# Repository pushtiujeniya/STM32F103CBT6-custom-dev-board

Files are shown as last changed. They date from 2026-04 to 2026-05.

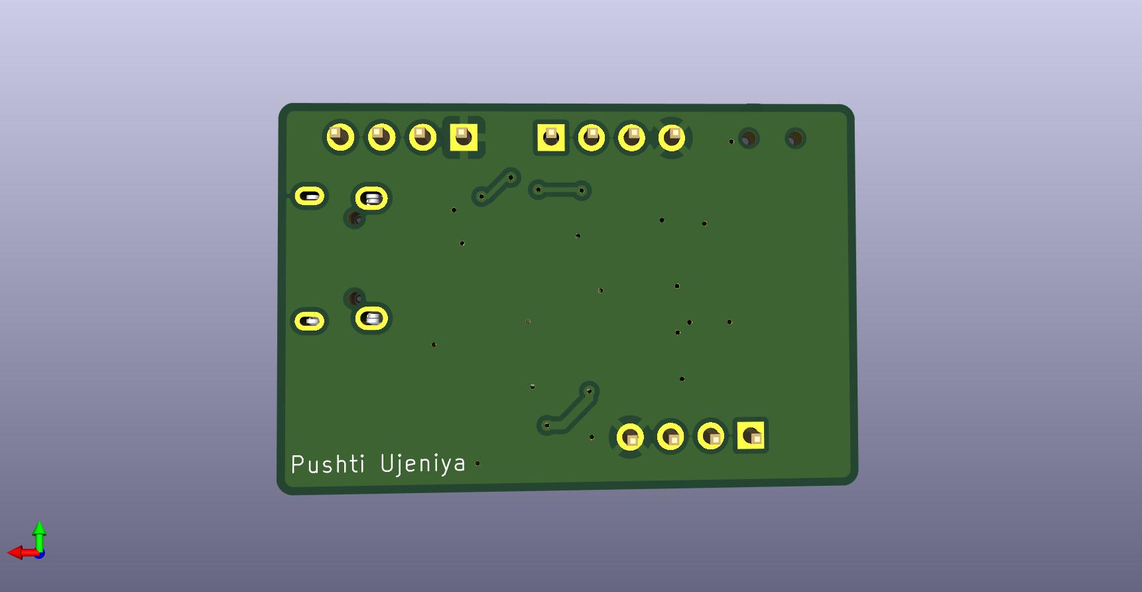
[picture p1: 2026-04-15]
3D_view/3D_bottom view.jpg

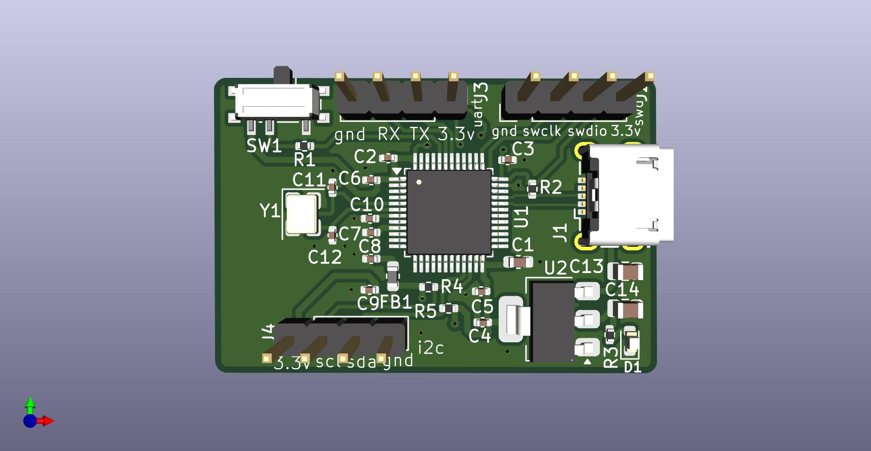
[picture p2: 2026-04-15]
3D_view/3D_top view.jpg

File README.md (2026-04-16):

# **STM32F103 custom development board**

This project contains custom development board based on the STM32F103 microcontroller.This baord created using kicad 9.0 software with proper routing , signal integrity, differential pair routing of USB connection.

## **Features**
- STM32F103 microcontroller
- Onboard 3.3V linear voltage regulator(AMS1117-3.3)
- Onboard Led indication on 3.3V power supply
- Micro USB interface for power and communication
- SWD interfacae for debugging and programming
- UART and I2C breakout headers
- Decoupling capacitors placed for stable operation
- External crystal oscillator with load capacitors
- MCU reser switch
- Clean PCB layout with proper grouding and differential routing for mico USB connection
- Board size: 35.5 mm X 23.6 mm

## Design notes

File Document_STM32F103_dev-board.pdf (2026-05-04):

STM32F103CBT6

STM32F103 custom development board
This project contains custom development board based on the STM32F103 microcontroller.This baord created using kicad 9.0 software with proper routing , signal integrity, differential pair routing of USB connection.

Features
STM32F103 microcontroller
Onboard 3.3V linear voltage regulator(AMS1117-3.3) Onboard Led indication on 3.3V power supply Micro USB interface for power and communication SWD interfacae for debugging and programming UART and I2C breakout headers
Decoupling capacitors placed for stable operation
External crystal oscillator with load capacitors
MCU reser switch
Clean PCB layout with proper grounding and differential routing for mico USB connection Board size: 35.5 mm X 23.6 mm

LDO power supply section

Pinout of LDO AMS1117-3.3
Vin
Vout
Gnd

Both vin and vout need decoupling capacitors connected with it Gnd connects directly with ground
Input voltage= 4.5V to 12V DC
Output voltage=3.3V

Here LDO is linear voltage regulator it converts the extra voltage into heat So as the heat is generating the efficiency decreases

Here 5v to 3.3v LDO conversion
Efficiency = vout/vin
=3.3/ 5
=66%
AMS1117-3.3
This LDO will give output as 3.3 v

As its voltage drop is high .>=1v
Here both vin and vout pins of the LDO needed decoupling capacitors
In datasheet 10uF decoupling capacitors mentioned which is minimum value of capacitor need to use
So for good stability 22uF is used
This generated 3.3V output of LDO is goes into MCU power on pin
By giving 3.3V the MCU gets power on
There is one LED with 1.5kohm resistor protection is connected at 3.3v output of an LDO to identify that 3.3v is available in LDO

USB_B micro

Pinout of USB B micro connector

D+ for data +
D- for data -
GND for ground
Vbus for +5v from USB
Shield= connects with gnd
Shield is metal holo part of the USB
Or shield can be connected with one resistor and one capacitor value for good ESD protection ID for different mode
ID=floating= device mode
ID=connect with GND= host mode

In device mode the host will control to USB Usb will respond to the host (PC)

Host mode
In this host will control everything

Pin 32 and pin33 of stm32f103 is used for USB connection

WHY PULL UP RESISTOR ON USB_D+ LINE REQUIRED
This pull up resistor tells to the host that device is connected
Without pull up resistor the host (PC) won’t know that device is connected

If pull up resistor is connected with D+ and D-

If pull up resistor is connected with D+ then USB will work in full speed (12 mbps)
If pull up resistor is connected with D- then USB will work in low speed device (1.5 mbps)

STM32F103 MCU

Pinout

vdd= digital power 3.3v
vss=gnd
vdda= analog power 3.3v
vssa= gnd
NRST= reset (active low)
BOOT0= boot mode select
PB2 (BOOT1) = secondary boot config

Clock pins
PD0= oscillator input= crystal input
PD1= oscillator output= crystal output Connect 4 to 16mhz external crystal range

Port A(PA0 to PA15)
ADC input, USART, SPI etc

Port B(PB0 to PB15)
I2c, spi, gpio

Port C( PC13 to PC15)
Low power pins , used for LED connection Switch connection

PA9= USART TX
PA10= USART RX

PB6= I2C SCL
PB7=I2C SDA

PA5= SPI SCK
PA6= SPI MISO
PA7= SPI MOSI

PA13= SWDIO
PA14=SWCLK
Used for programming via st link

PC14
PC15 CRYSTAL

VBAT= back up battery connection
If battery is not connected then connect vbat with your input voltage either vdd or VDDA

Name structure of STM32
STM32F103
This 1 indicate low power speed

STM32F401
This 4 indicate higher speed compare to STM32F103

STM32L= L for ultra low power
STM32WB= WB indicates for wireless conenction supported MCU

VDD pin of the MCU
Each vdd pin required decoupling capacitors connected with it 0.1uf for each vdd pin to remove high frequency noise
10uf for bulk energy storage and to remove low frequency noise

VDDA pin for analog input
VDD for digital power

Why VDD and VDDA two separate supply given in MCU
If VDD and VDDA is not separate out then digital noisy signal enter into analog circuits which cause wrong measurement of the ADC value
This occurs wrong value for sensors
So VDDA is very sensitive to noise so must be clean and need to separate out the power supply from VDD

WHY FERRITE BEAD IS CONNECTED ONLY WITH VDDA SECTION
As the ferrite bead will stop noise to enter into digital section and will provide clean path Digital circuit needs fast switching and instant current if ferrite bead is connected with digital circuit then it will resist high current frequency and will slow down the current delivery therefore don’t connect ferrite bead with it

PIN HEADER FOR SWD, USART, I2C

For debugging perspective there is swd pin header connection

Usart, i2c are for external connection of sensors

PCB LAYOUT
2 layer pcb

The track width for power rail is 0.5mm which is capable of carrying current up to 2A And other signal track width is 0.3mm

Front copper layer and bottom copper layer is apply with gnd solid plane

GND vias connection
Every gnd pad is connected with gnd vias so that the return current path loop remain short and tight

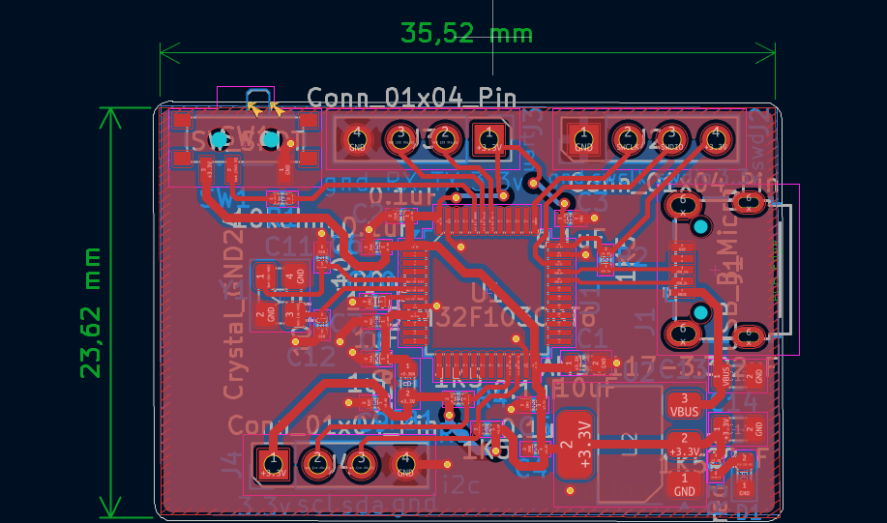
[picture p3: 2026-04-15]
Layout_front.png

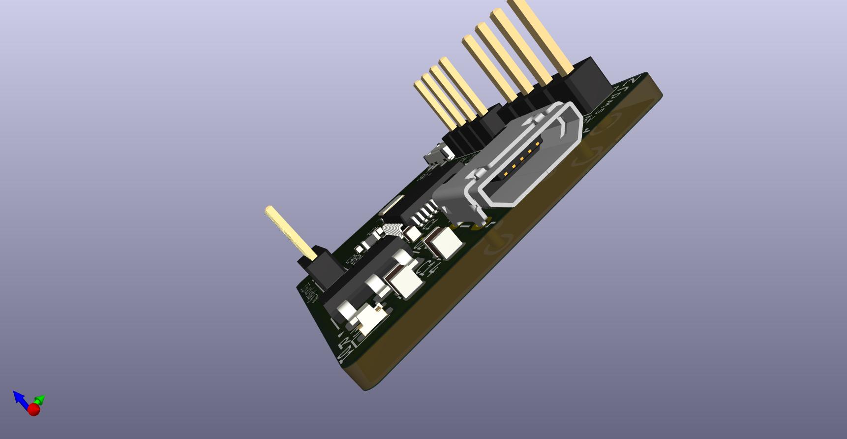
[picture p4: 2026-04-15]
3D_view/3D_microusb view.jpg

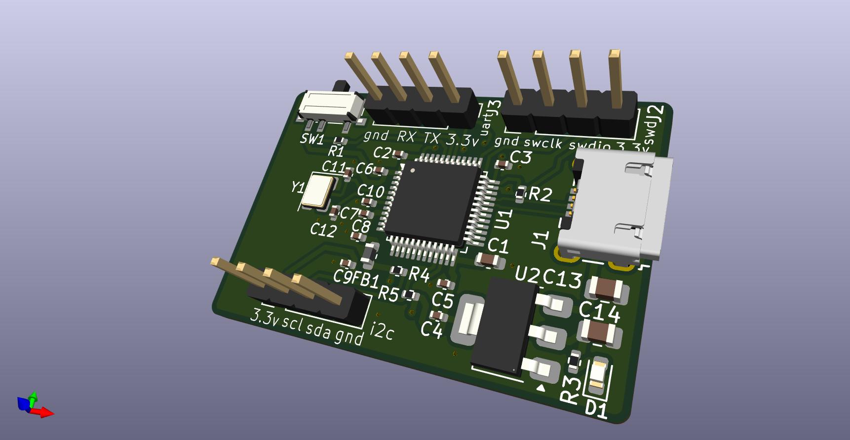
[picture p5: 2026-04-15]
3D_view/3D_side view.jpg

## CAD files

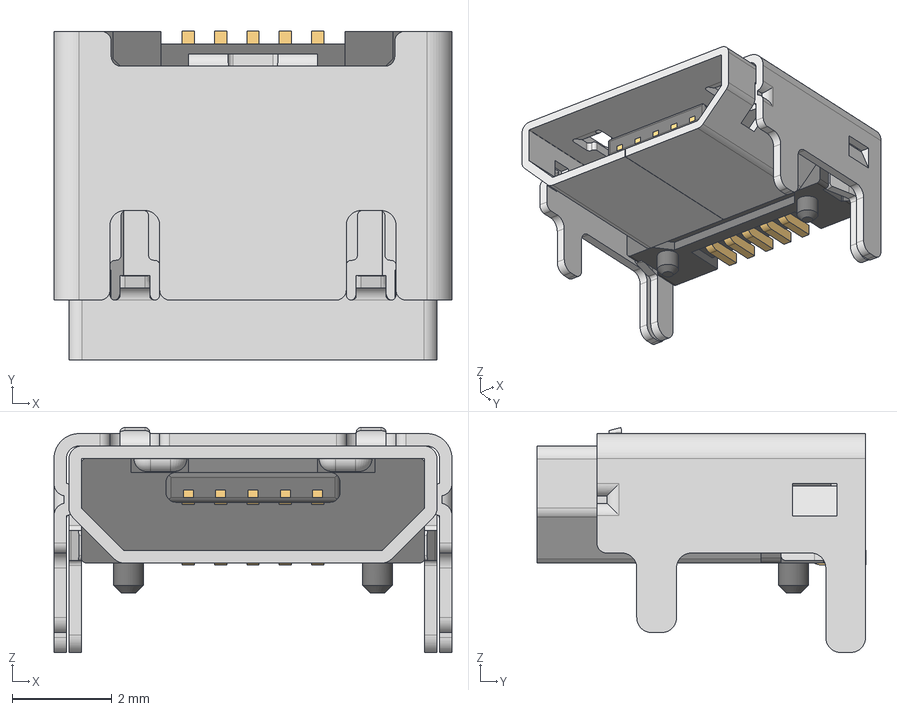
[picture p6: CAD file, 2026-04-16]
External library/629105150521+%28rev1%29.stp
8.00 x 6.60 x 4.52 mm
629105150521_Housing
629105150521_Pin1 x 4
629105150521_Pin2
629105150521_Shielding2
629105150521_Shielding

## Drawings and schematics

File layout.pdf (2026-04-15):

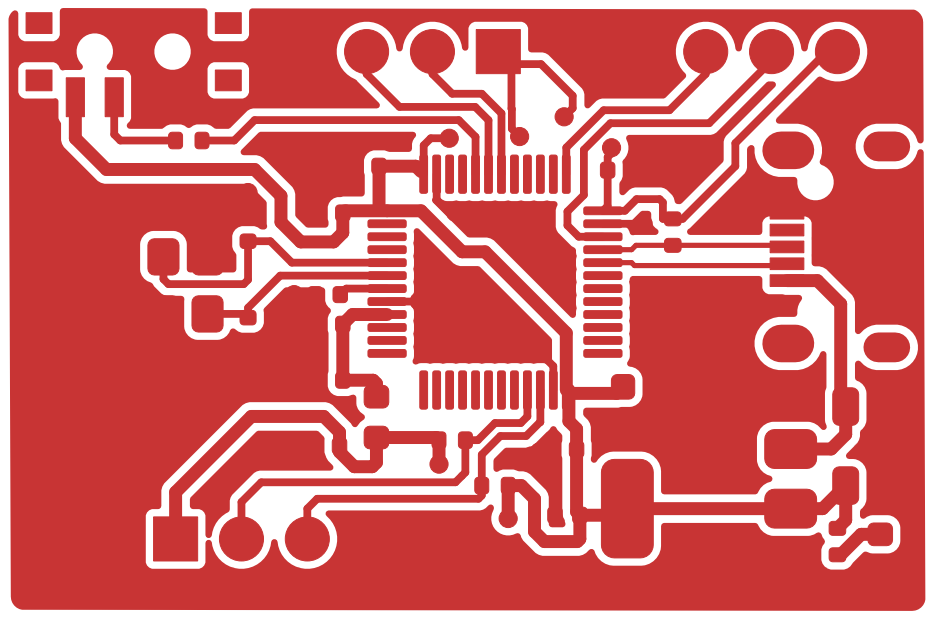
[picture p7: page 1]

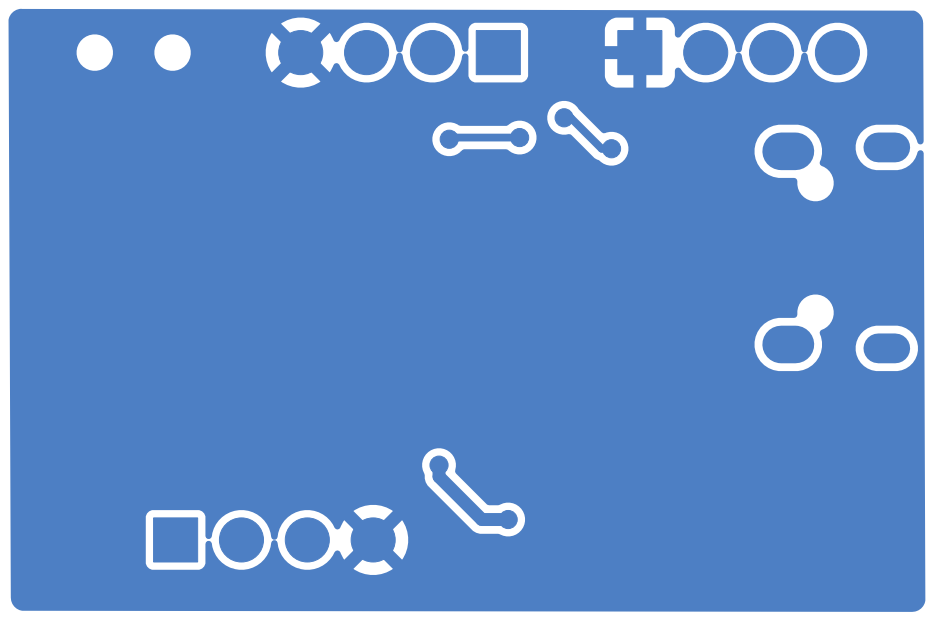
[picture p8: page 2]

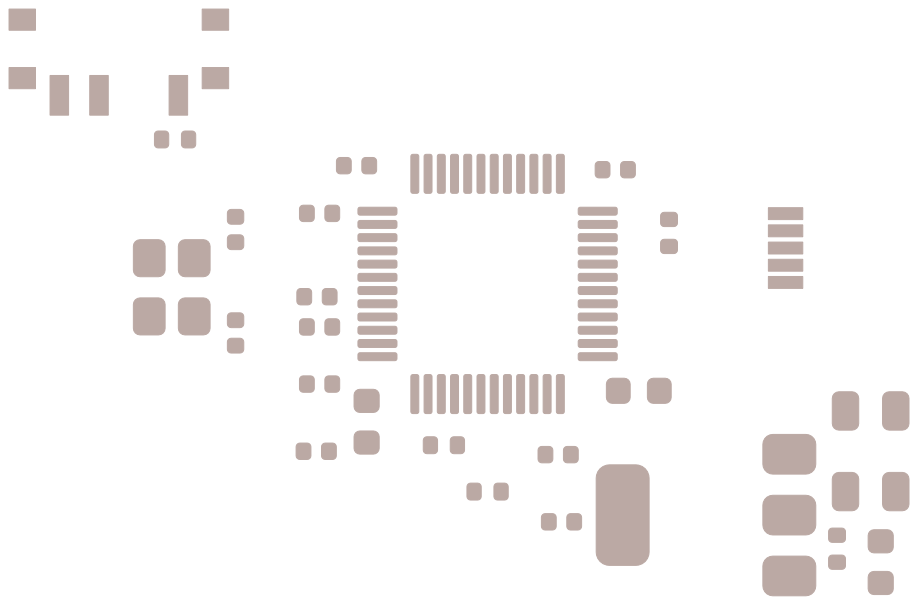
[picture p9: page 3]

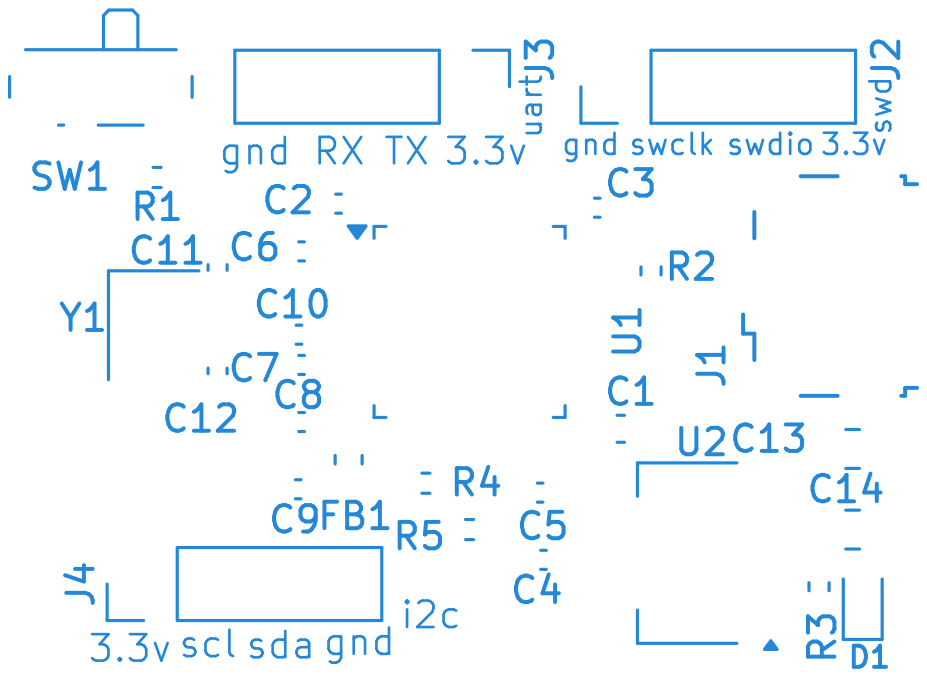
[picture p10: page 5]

uart swd gnd RX TX 3.3v gnd swclk swdio 3.3v 3.3v scl sda gnd

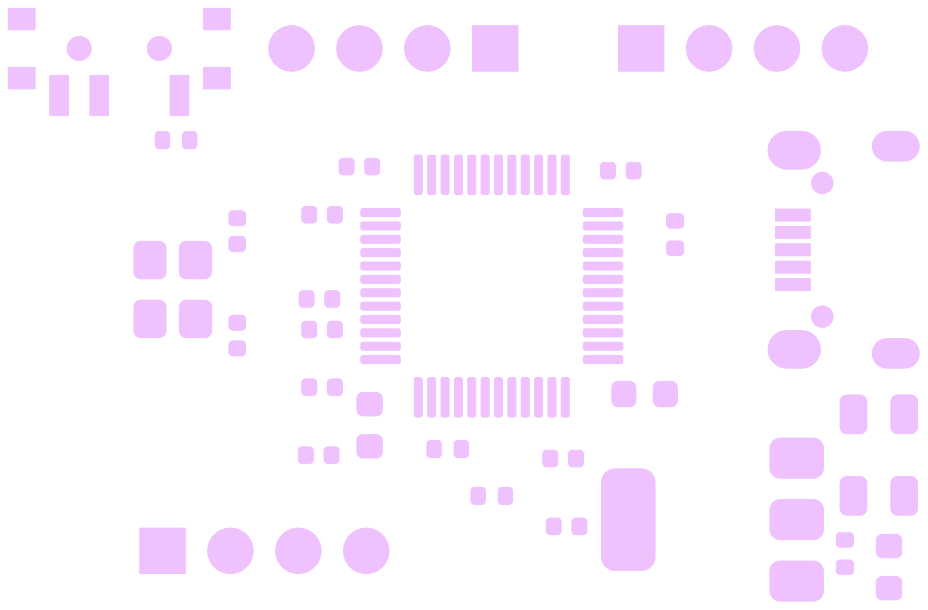
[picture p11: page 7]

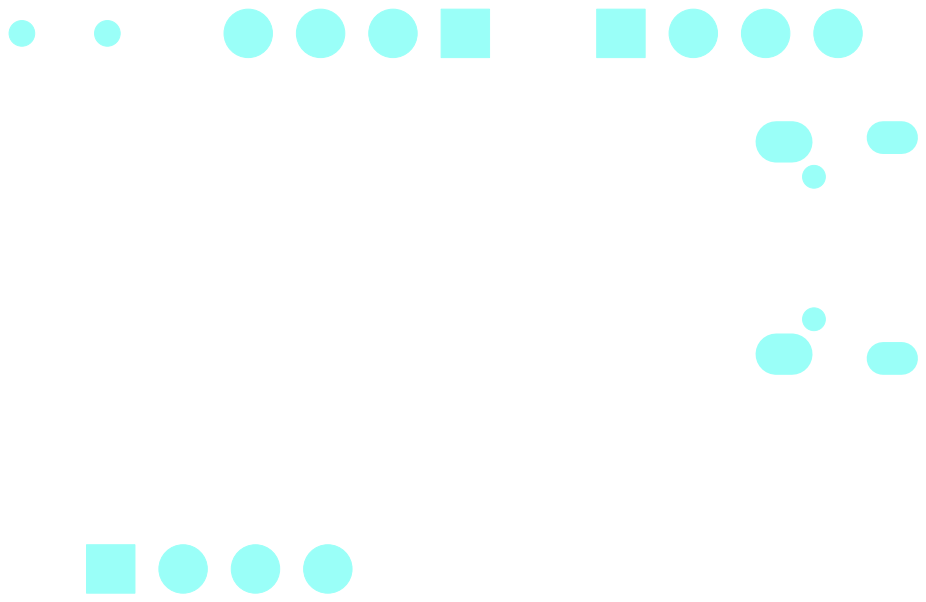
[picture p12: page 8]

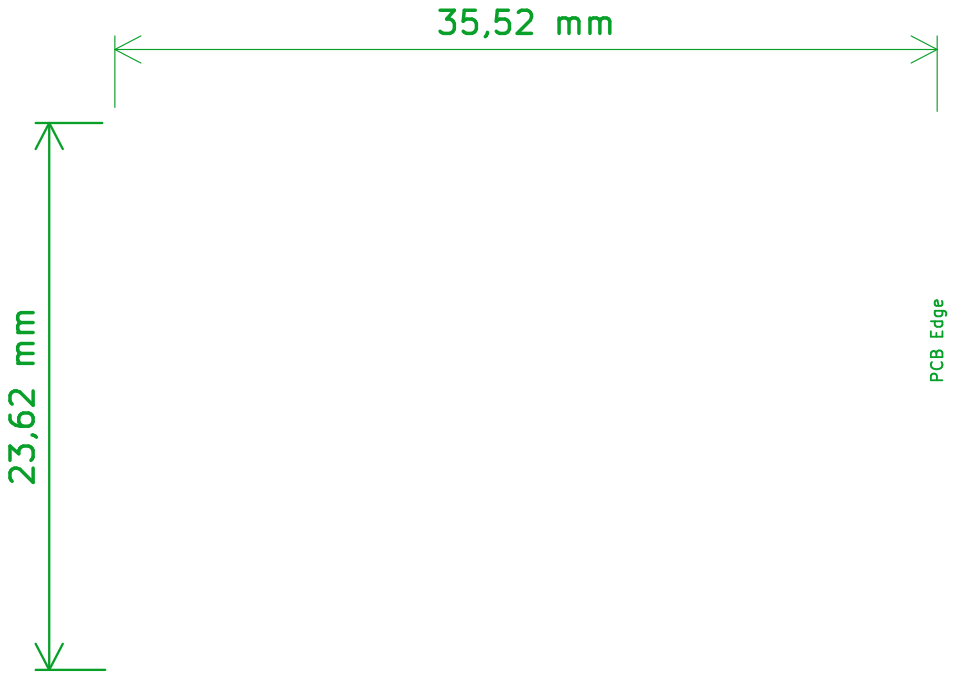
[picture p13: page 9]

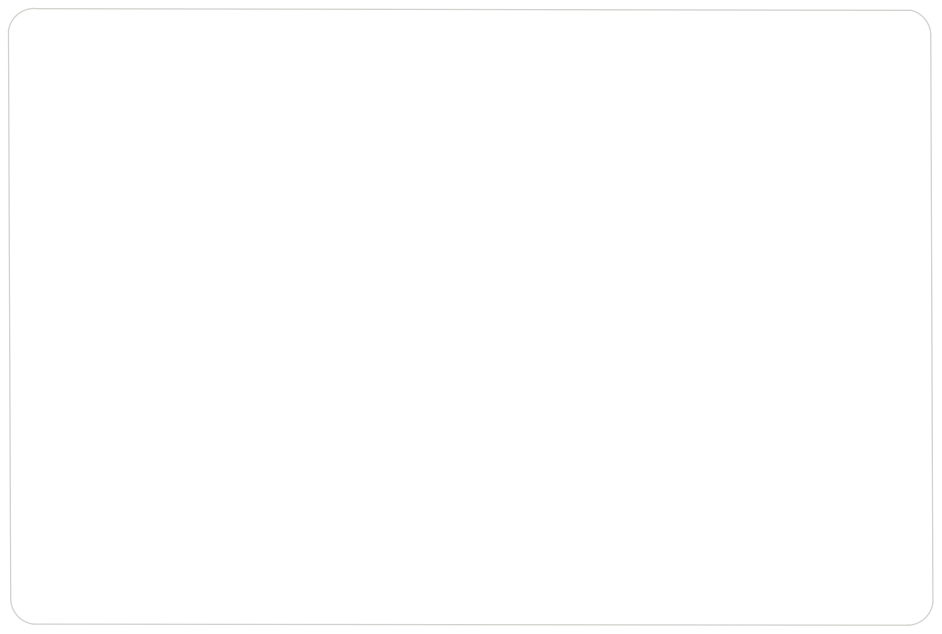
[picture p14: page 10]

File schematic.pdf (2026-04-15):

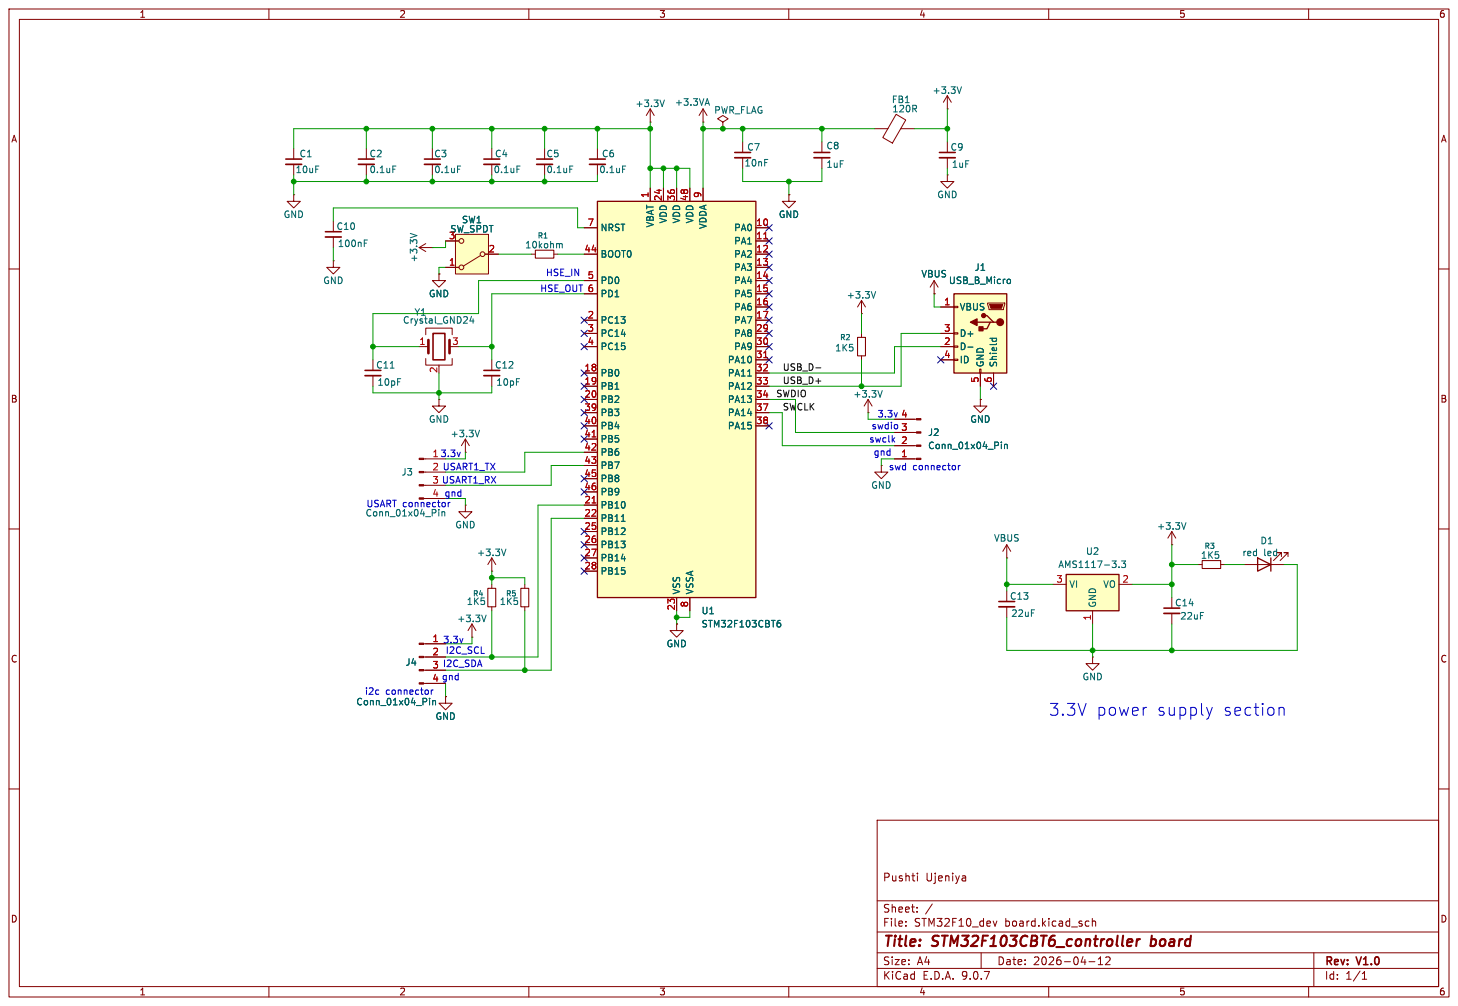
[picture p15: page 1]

1 VDD 24 VDD 36 VSS 23 VDD 48 VSSA

1 VO 2 U2 AMS1117-3.3 R2 1K5 VBUS NRST 7 BOOT0 44 PD0 5 PD1 6 PC13 2 PC14 3 PC15 4 PB0 18 PB1 19 PB2 20 PB3 39 PB4 40 PB5 41 PB6 42 PB7 43 PB8 45 PB9 46 PB10 21 PB11 22 PB12 25 PB13 26 PB14 27 PB15 28 VBAT

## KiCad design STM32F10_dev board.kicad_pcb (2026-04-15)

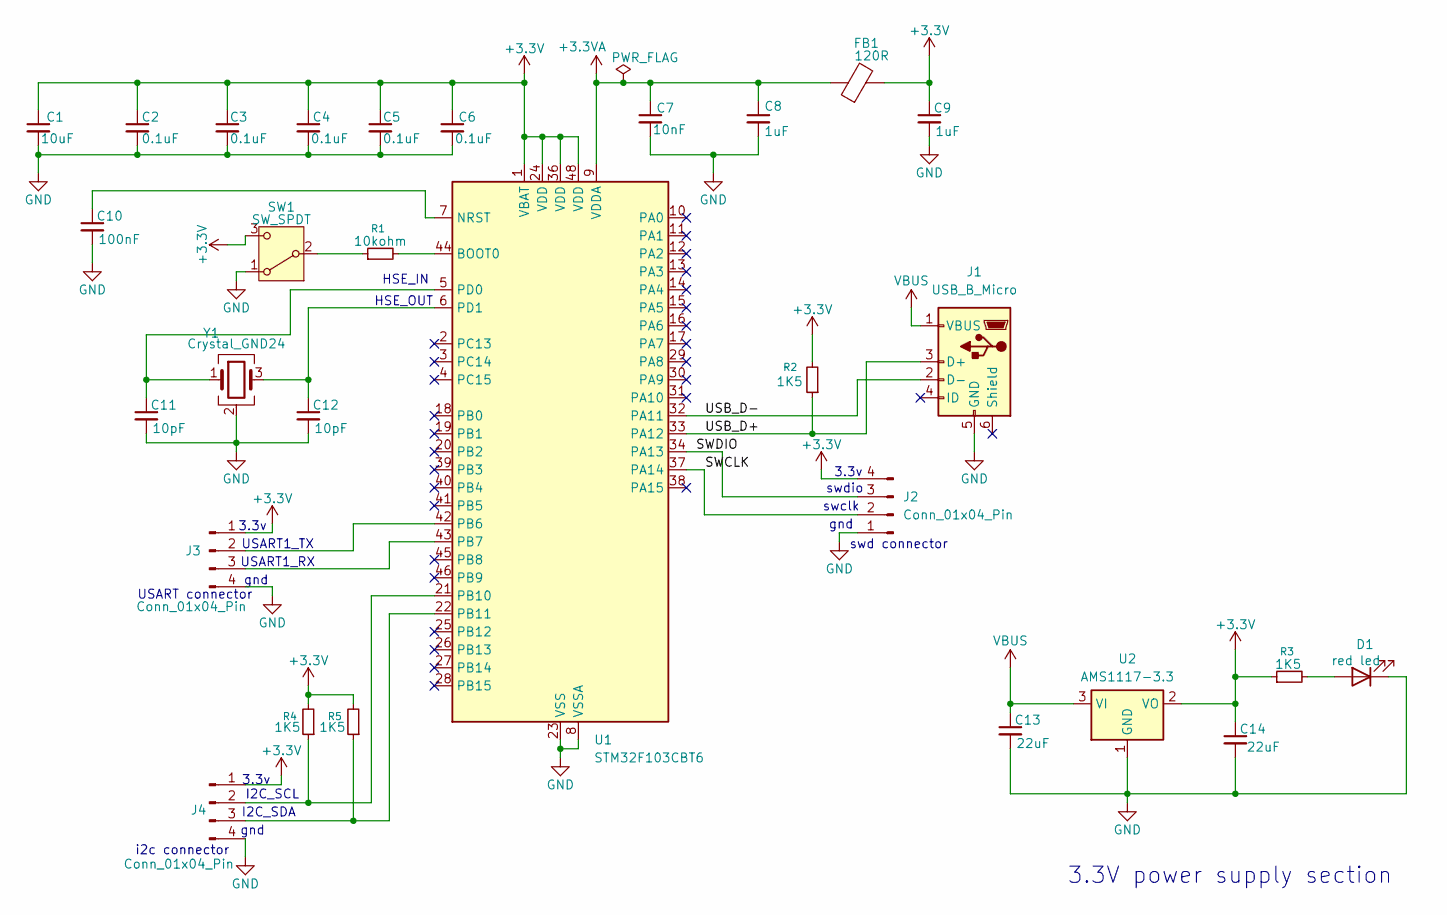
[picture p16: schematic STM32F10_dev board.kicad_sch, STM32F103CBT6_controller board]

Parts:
C1: 10uF; C_0603_1608Metric
C2, C3, C4, C5, C6: 0.1uF; C_0402_1005Metric
C7: 10nF; C_0402_1005Metric
C8, C9: 1uF; C_0402_1005Metric
C10: 100nF; C_0402_1005Metric
C11, C12: 10pF; C_0402_1005Metric
C13, C14: 22uF; C_0805_2012Metric
D1: red led; LED_0603_1608Metric
FB1: 120R; L_0603_1608Metric
J1: USB_B_Micro; USB_Micro-B_Wuerth_629105150521
J2, J3, J4: Conn_01x04_Pin; PinHeader_1x04_P2.54mm_Vertical
R1: 10kohm; R_0402_1005Metric
R2, R3, R4, R5: 1K5; R_0402_1005Metric
SW1: SW_SPDT; SW_SPDT_PCM12
U1: STM32F103CBT6; LQFP-48_7x7mm_P0.5mm
U2: AMS1117-3.3; SOT-223-3_TabPin2
Y1: Crystal_GND24; Crystal_SMD_3225-4Pin_3.2x2.5mm

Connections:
+3.3V: C1.1, C2.1, C3.1, C4.1, C5.1, C6.1, C9.1, C14.1, FB1.2, J2.4, J3.1, J4.1, R2.2, R3.1, R4.2, R5.2, SW1.3 (C), U1.1 (VBAT), U1.24 (VDD), U1.36 (VDD), U1.48 (VDD), U2.2 (VO)
+3.3VA: C7.1, C8.1, FB1.1, U1.9 (VDDA)
/SWCLK: J2.2, U1.37 (PA14)
/SWDIO: J2.3, U1.34 (PA13)
/USB_D+: J1.3 (D+), R2.1, U1.33 (PA12)
/USB_D-: J1.2 (D-), U1.32 (PA11)
GND: C1.2, C2.2, C3.2, C4.2, C5.2, C6.2, C7.2, C8.2, C9.2, C10.2, C11.2, C12.2, C13.2, C14.2, D1.1 (K), J1.5 (GND), J2.1, J3.4, J4.4, SW1.1 (A), U1.8 (VSSA), U1.23 (VSS), U1.35 (VSS), U1.47 (VSS), U2.1 (GND), Y1.2 (G), Y1.4 (G)
unnamed: D1.2 (A), R3.2
unnamed: J3.2, U1.42 (PB6)
unnamed: J3.3, U1.43 (PB7)
unnamed: J4.2, R4.1, U1.21 (PB10)
unnamed: J4.3, R5.1, U1.22 (PB11)
unnamed: R1.1, SW1.2 (B)
unnamed: R1.2, U1.44 (BOOT0)
unnamed: C10.1, U1.7 (NRST)
unnamed: C11.1, U1.5 (PD0), Y1.1
unnamed: C12.1, U1.6 (PD1), Y1.3
VBUS: C13.1, J1.1 (VBUS), U2.3 (VI)

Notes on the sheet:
USART1_RX
swclk
3.3v
3.3v
i2c connector
swd connector
USART connector
swdio
HSE_OUT
3.3V power supply section
HSE_IN
gnd
USART1_TX
I2C_SCL
gnd
I2C_SDA

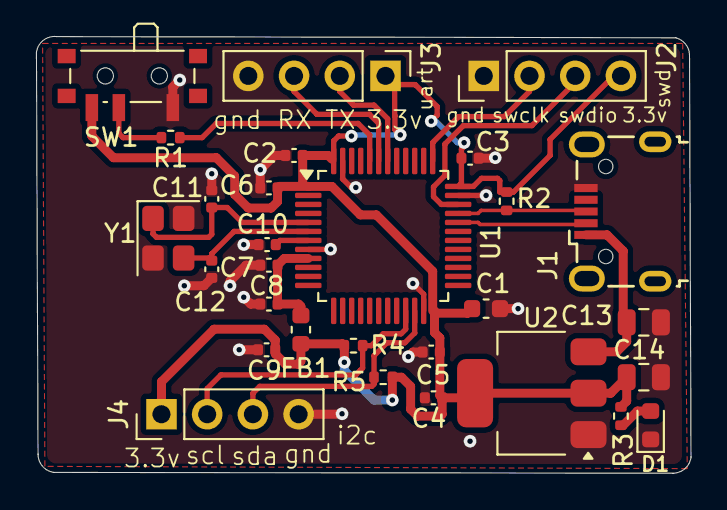
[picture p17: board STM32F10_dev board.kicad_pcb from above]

Board: 2 copper layers, 36.4 x 24.3 mm, 29 parts (0 on the bottom side), 18 nets.

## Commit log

2026-04-15 Add README for STM32F103 custom development board
    Added project description and features for STM32F103 board.
2026-04-15 Update README with additional features
    Added features and details about the STM32F103 development board.
2026-04-15 layout files added
    [STM32F10_dev board.kicad_pcb]
2026-04-15 schematic files added
    [STM32F10_dev board.kicad_sch]
2026-04-16 micro USB step file(3D model)
    [629105150521+%28rev1%29.stp]
2026-04-16 Add board size information to README
